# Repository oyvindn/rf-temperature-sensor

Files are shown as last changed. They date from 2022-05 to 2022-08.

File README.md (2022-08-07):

# Battery driven wireless temperature sensor

Arduino based battery driven wireless temperature sensor.

## Introduction

## ATmega328 on a breadboard

In order to save battery the ATmega328P is set to use its internal 8 MHz RC oscillator as a clock. This way we can set up a minimal circuit, eliminating the need for extra components like the the 16 MHz crystal. See the [From Arduino to a Microcontroller on a Breadboard](https://docs.arduino.cc/built-in-examples/arduino-isp/ArduinoToBreadboard) tutorial for instructions on how to burn a bootloader and setting up the minimal ATmega328 circuit on a breadboard.

## Hardware

* ATmega328P
* HopeRF RFM69CW 13DBM 868Mhz RF Transceiver Module
* DS18B20 Digital temperature sensor

## Arduino sketch dependencies

* [Arduino AVR Boards](https://github.com/arduino/ArduinoCore-avr)
* [RadioHead Packet Radio library for embedded microprocessors](http://www.airspayce.com/mikem/arduino/RadioHead/)
* [One Wire](https://github.com/PaulStoffregen/OneWire)
* [Arduino Library for Maxim Temperature Integrated Circuits](https://github.com/milesburton/Arduino-Temperature-Control-Library)
* [Low-Power](https://github.com/rocketscream/Low-Power)

## Compile, upload and monitor ATmega328p using the Arduino CLI

### Add secrets
Copy `arduino_secrets.h.example` to `arduino_secrets.h` and change the example secret values.

### Download and install Arduino IDE and/or CLI
[Arduino CLI](https://arduino.github.io/arduino-cli/) is an all-in-one solution that provides Boards/Library Managers, sketch builder, board detection, uploader, and many other tools needed to use any Arduino compatible board and platform from command line or machine interfaces.

## Download and burn bootloader
Download the [ATmega328 on a breadboard bootloader](https://www.arduino.cc/en/uploads/Tutorial/breadboard-1-6-x.zip) and follow the instructions in the [From Arduino to a Microcontroller on a Breadboard](https://docs.arduino.cc/built-in-examples/arduino-isp/ArduinoToBreadboard) tutorial.

### Install library dependecies
Install the library dependencies listet above.

### Compile sketch
`arduino-cli compile -b breadboard:avr:atmega328bb`

### Upload sketch to ATmega328P using e.g. a FTD-232R-3V3 USB to TTL Serial Cable:
`arduino-cli upload -p /dev/cu.usbserial-FTC0DLEV -b breadboard:avr:atmega328bb -v`

### Open the serial monitor
`arduino-cli monitor -p /dev/cu.usbserial-FTC0DLEV -c baudrate=115200`

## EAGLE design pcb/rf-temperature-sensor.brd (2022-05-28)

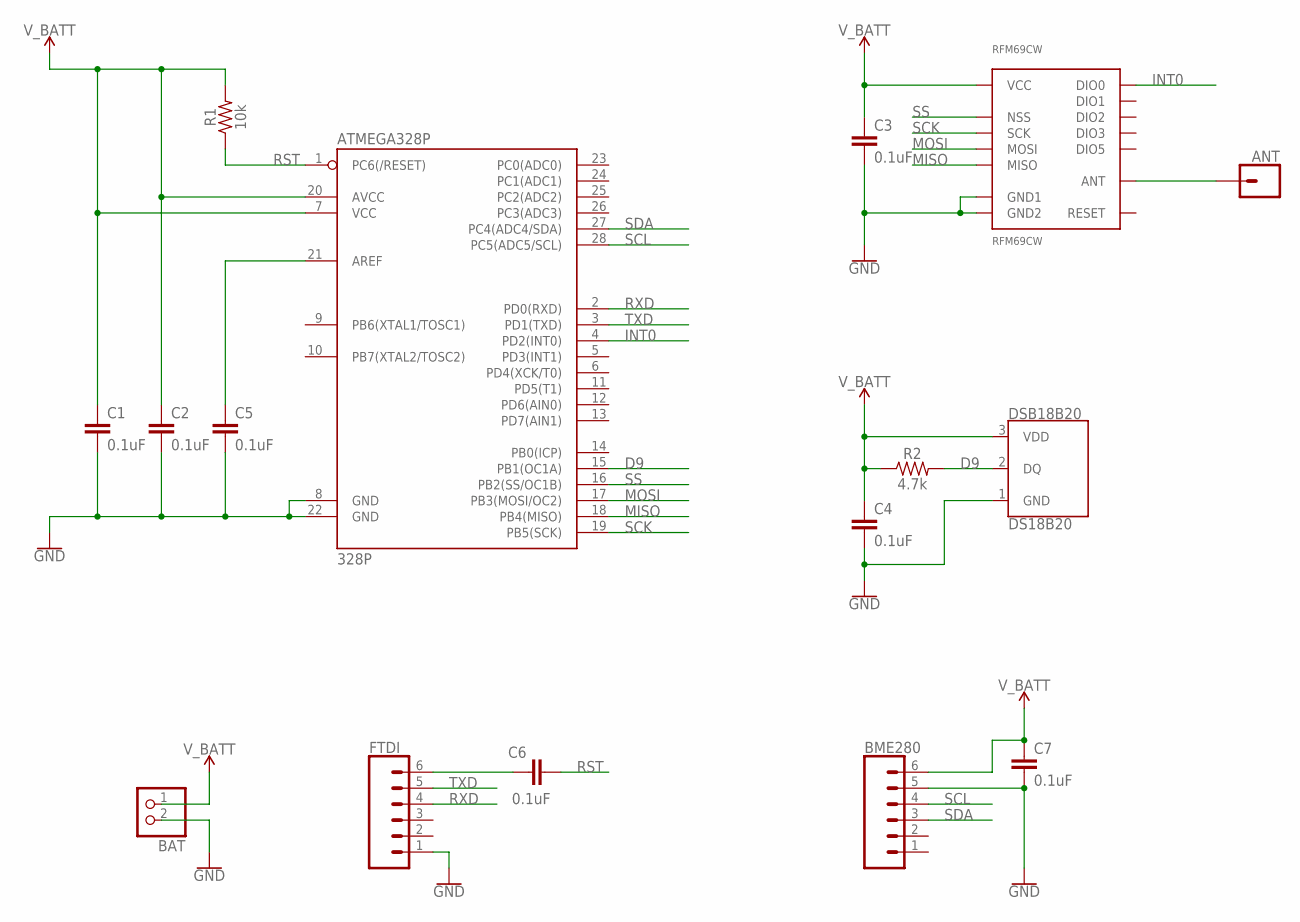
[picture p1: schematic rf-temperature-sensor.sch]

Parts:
ANT: CONN_01; 1X01
ATMEGA328P: 328P; DIP28
BAT: JST_2PIN-THM-RA; JST-PH-2-THM-RA
BME280: CONN_06SILK_FEMALE_PTH; 1X06
C1, C2, C3, C4, C5, C6, C7: 0.1uF; 0603
DSB18B20: DS18B20; TO-92-AMMO
FTDI: CONN_06SILK_FEMALE_PTH; 1X06
R1: 10k; 0603
R2: 4.7k; 0603
RFM69CW: RFM69CW

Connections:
D9: ATMEGA328P.15 (PB1(OC1A)), DSB18B20.2 (DQ), R2.2
GND: ATMEGA328P.8 (GND), ATMEGA328P.22 (GND), BAT.2 (1), BME280.5, C1.2, C2.2, C3.2, C4.2, C5.2, C7.2, DSB18B20.1 (GND), FTDI.1, RFM69CW.GND@1 (GND1), RFM69CW.GND@2 (GND2)
INT0: ATMEGA328P.4 (PD2(INT0)), RFM69CW.DIO0
MISO: ATMEGA328P.18 (PB4(MISO)), RFM69CW.MISO
MOSI: ATMEGA328P.17 (PB3(MOSI/OC2)), RFM69CW.MOSI
unnamed: ATMEGA328P.21 (AREF), C5.1
unnamed: ANT.1, RFM69CW.ANT
unnamed: C6.1, FTDI.6
RST: ATMEGA328P.1 (PC6(/RESET)), C6.2, R1.1
RXD: ATMEGA328P.2 (PD0(RXD)), FTDI.4
SCK: ATMEGA328P.19 (PB5(SCK)), RFM69CW.SCK
SCL: ATMEGA328P.28 (PC5(ADC5/SCL)), BME280.4
SDA: ATMEGA328P.27 (PC4(ADC4/SDA)), BME280.3
SS: ATMEGA328P.16 (PB2(SS/OC1B)), RFM69CW.NSS
TXD: ATMEGA328P.3 (PD1(TXD)), FTDI.5
V_BATT: ATMEGA328P.7 (VCC), ATMEGA328P.20 (AVCC), BAT.1 (2), BME280.6, C1.1, C2.1, C3.1, C4.1, C7.1, DSB18B20.3 (VDD), R1.2, R2.1, RFM69CW.VDD (VCC)

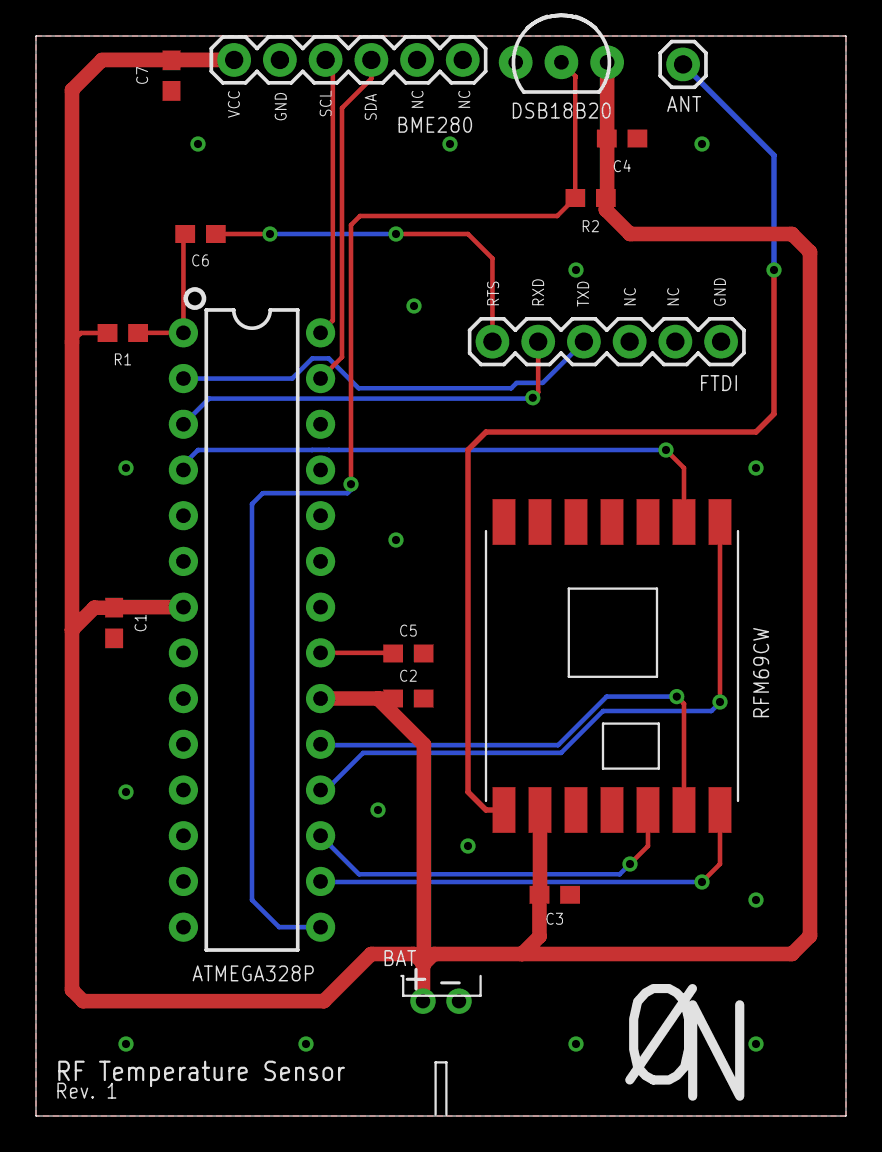
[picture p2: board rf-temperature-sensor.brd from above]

Board: 2 copper layers, 45.0 x 60.0 mm, 16 parts (0 on the bottom side), 16 nets.

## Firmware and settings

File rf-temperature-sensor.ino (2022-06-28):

#include <Arduino.h>
#include <LowPower.h>

#include <SPI.h>
#include <RH_RF69.h>
#include <RHReliableDatagram.h>

#define USE_BME280 true

#if USE_BME280
#include <Wire.h>
#include <Adafruit_Sensor.h>
#include <Adafruit_BME280.h>
#else
#include <OneWire.h>
#include <DallasTemperature.h>
#endif

#include "arduino_secrets.h"

#define DS18B20_TEMPERATURE_SENSOR_PIN 9

#define RF_INTERRUPT_PIN 2
#define RF_FREQUENCY 868.00
#define RF_GATEWAY_ADDRESS 1
#define RF_NODE_ADDRESS 2

#define SLEEP_CYCLES 38 // times 8 seconds power down

RH_RF69 rf69Driver(PIN_SPI_SS, RF_INTERRUPT_PIN);
RHReliableDatagram radioManager(rf69Driver, RF_NODE_ADDRESS);

#if USE_BME280
Adafruit_BME280 bme;
#else
OneWire oneWire(DS18B20_TEMPERATURE_SENSOR_PIN);
DallasTemperature temperatureSensors(&oneWire);
#endif

void setup()
{
  Serial.begin(115200);
  while (!Serial)
    ;

  initRadio();

#if USE_BME280
  initBME280();
#else
  temperatureSensors.begin();
#endif
}

void loop()
{
  char message[50];

  long vcc = readVcc();

#if USE_BME280
  bme.takeForcedMeasurement();
  float temperature = bme.readTemperature();
  float humidity = bme.readHumidity();
  float pressure = bme.readPressure() / 100.0F;

  char temperatureStr[10];
  dtostrf(temperature, 1, 2, temperatureStr);

  char humidityStr[10];
  dtostrf(humidity, 1, 0, humidityStr);

  char pressureStr[10];
  dtostrf(pressure, 1, 0, pressureStr);

  sprintf(message, "THPV;%s;%s;%s;%d", temperatureStr, humidityStr, pressureStr, vcc);
#else
  float temperature = readDS18B20Temperature();
  char temperatureStr[10];
  dtostrf(temperature, 1, 2, temperatureStr);
  sprintf(message, "TV;%s;%d", temperatureStr, vcc);
#endif

  radioManager.sendtoWait((uint8_t *)message, sizeof(message), RF_GATEWAY_ADDRESS);
  powerDown(SLEEP_CYCLES);
}

#if !USE_BME280
float readDS18B20Temperature()
{
  temperatureSensors.requestTemperatures();
  float temp = temperatureSensors.getTempCByIndex(0);
  return temp;
}
#endif

long readVcc()
{
  // Read 1.1V reference against AVcc
  // set the reference to Vcc and the measurement to the internal 1.1V reference
  ADMUX = _BV(REFS0) | _BV(MUX3) | _BV(MUX2) | _BV(MUX1);

  delay(2);            // Wait for Vref to settle
  ADCSRA |= _BV(ADSC); // Start conversion
  while (bit_is_set(ADCSRA, ADSC))
    ; // measuring

  uint8_t low = ADCL;  // must read ADCL first - it then locks ADCH
  uint8_t high = ADCH; // unlocks both

  long result = (high << 8) | low;

  // Vbat = 1100mV * 1024 / ADC value
  result = 1125300L / result; // Calculate Vcc (in mV); 1125300 = 1.1*1023*1000
  return result;              // Vcc in millivolts
}

void powerDown(int times)
{
  rf69Driver.sleep();

  for (int i = 0; i < times; i++)
  {
    LowPower.powerDown(SLEEP_8S, ADC_OFF, BOD_OFF);
  }
}

void initRadio()
{
  if (radioManager.init())
  {
    Serial.println("[RFM69] Init success");
  }
  else
  {
    Serial.println("[RFM69] Init failed");
  }
  // Defaults after init are 434.0MHz, modulation GFSK_Rb250Fd250, +13dbM (for low power module)
  if (rf69Driver.setFrequency(RF_FREQUENCY))
  {
    Serial.print("[RFM69] Frequency set to ");
    Serial.print(RF_FREQUENCY);
    Serial.println("MHz");
  }
  else
  {
    Serial.println("[RFM69] Failed to set frequency");
  }

  uint8_t encryptionKey[] = SECRET_RF_ENCRYPTION_KEY;
  rf69Driver.setEncryptionKey(encryptionKey);
}

#if USE_BME280
void initBME280()
{
  if (!bme.begin(0x76))
  {
    Serial.println("[BME280] No BME280 device found!");
  }
  else
  {
    bme.setSampling(Adafruit_BME280::MODE_FORCED,
                    Adafruit_BME280::SAMPLING_X1, // temperature
                    Adafruit_BME280::SAMPLING_X1, // pressure
                    Adafruit_BME280::SAMPLING_X1, // humidity
                    Adafruit_BME280::FILTER_OFF);
  }
}
#endif

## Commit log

2022-03-16 Flush serial before powering down
2022-03-17 Power down for 5 minutes (38 times 8 seconds)
2022-03-18 Remove serial print in main loop to save battery
2022-04-04 Add support for BME280 Humidity, Barometric Pressure and Temperature sensor
2022-04-08 Add message type and send all sensor data
2022-05-28 add pcb design
    [rf-temperature-sensor.brd, rf-temperature-sensor.sch]
2022-06-28 Add MHz on print output

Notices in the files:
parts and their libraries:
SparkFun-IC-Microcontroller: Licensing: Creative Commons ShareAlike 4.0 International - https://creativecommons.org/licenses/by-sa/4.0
